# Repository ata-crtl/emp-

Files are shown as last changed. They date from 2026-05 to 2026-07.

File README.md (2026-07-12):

**COMPLETE EMP BUILD**

  This is a low energy through hole electro magnetic pulse generator built for educational purposes.
  It uses inductive Kicback from a simple air core coil to generate broad band pulse that can glitch or reset unshielded digital circuits. Flip the top saftey , then you hold down the trigger for 2 seconds to fire max.



Assembly 1 (19)

Onshape link = https://cad.onshape.com/documents/e3ea2a8dce756d3e28ba0ed2/w/b44164742f645132d3413e84/e/23451d8a78cdce11df78b1ae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
  ---

 ## Table of Contents

- [What is this?](#what-is-this)
- [Why I built it](#why-i-built-it)
- [How it works (in 30 secs)](#how-it-works-in-30-secs)
- [Images and diagrams](#images-and-diagrams)
- [Assembly instructions](#assembly-instructions)
  - [1. Solder the PCB](#1-solder-the-pcb)
  - [2. Wind the coil](#2-wind-the-coil)
  - [3. Prepare the enclosure](#3-prepare-the-enclosure)
  - [4. Final assembly](#4-final-assembly)
- [Safety precautions](#safety-precautions)

---

## What is this?
 A compact, battery powered device that creates a rapid magnetic field collapse,radiating an electro magnetic pulse strong enough to inter fere with nearby digital electronics.It is not a weapon.EDUCTIONAL  USE ONLY

**KEY SPECS**
|parameter|Value|
|---|---|
|Pulse voltage at coil|>200V|
|Effective range |20-30cm(glitch)|
|power supply|3s lipo(11.1v)|
|Max fire time|2 seconds(thermal limit) more = you have 3 seconds to get out  :)|

---

## Why I built it
I always saw lots of tutorials on youtube and always thought how cool they looked.So i thought why not build it, but most of the tutorials on youtube were either weak emps or were very vauge on how to build it.

---
## How it works (in 30 secs)
- 1. A boost converter charges a bank of capacitors to 18V
  2. A 555 timer generates a short pulse,when you press the button
  3. That pulse drives a tc4420 gate driver which turns on the mosfet
  4. Current builds up at the air core coil for like a millisecond
  5. when the mosfet turns of the magnetic field collapses
  6. This makes a voltage spike  which goes over 200v and radiates abroad band emp

---

## Images and diagrams




AISelect_20260712_214746_Samsung Notes
AISelect_20260712_220100_Samsung Notes

AISelect_20260712_215529_Samsung Notes
---
## Assembly instructions
Get your pcb made, the gerber files are in the github.All components are marked on the pcb.
 ## 1. Solder the PCB
1. solder in order of hight, solder in resistors(r1-r7),small ceramics(c1,c5,c7)
 - then u1,u2,u3
 - then d1,l1,j1,j2,j3,j4
 - capacitors,c2,c3,c4,c6 . mind the polarity
 - q1 mossfet last
   
  2.clean the board with isopropyl alcohol
   
## 2. Wind the coil

- 1.Cut 40 cm of the 14awg magnet wire

  2.find a 2cm diameter cylinder(pen.pipe ect)

  3.wind 12 tight turns,make sure they touch

  4.slide it of, wrap with electrical tape

  5. leave  5cm at the end and strip the enamel and tin

  6. twist the 2 leads together

  7. measure resistance. should be 1-3 ohms . if lower add a 1 ohm resistor in series.

 ## 3. Prepare the enclosure
  
  -get the 3d printed case and line all the interior walls with copper foil other than the round emmesion  window at the front, cover the grills as well, but they are for heat dissapation.
  
  -overlap the foil and solder for continuity if needed

  ` solder 1 piece of wire to the foil and the other end to j4 for gnd
  
  ## 4. Final assembly
  1.mount the coil inside the case using hot glue,keep the twisted leads pointing towards the pcb area.
 

  2. place the battery in the top compartment , insert the heat set inserts , and screw the lid down, make sure the wires exit throught the bottom, slide on to the top of the case

  3.connect the  off board components.
 
  |Component A |Component B|
  |------------|-----------|
  |battery+|fuse|
  |fuse|master switch|
  |master switch|j2 pin 1 batt+(on pcb)|
  |battery-|j2 pin 2 batt-(on pcb)|
  |j3 pin 1 |one side of button|
  |other side of button|j3 pin2|
  |coil lead one side|j1|
  |coil lead other side|j2|

  4.place the pcb into the case and secure using the mounting holes ,use the m2 screws. 
  5. place the heat set inserts and screw the case shut.
  
----- 
## Safety precautions

. keep body and head 20-30 cm from emission window

.always discharge the coil after use, do not touch the coil while on

.do not use near pace makers , medical implants or sensitive lab equipment.

.keep a class c fire extinguisher nearby.

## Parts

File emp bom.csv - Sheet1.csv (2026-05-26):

Refrence | part | amount | Price(£) | link
pcb hardware
J1 | 2 pin screw terminal,5.08 pitch,throught hole | 1 | 0.99 | https://www.aliexpress.com/i/1005001666625465.html
J2 | 2 pin screw terminal,5.08 pitch,throught hole | 1 | 0.99 | https://www.aliexpress.com/i/1005001666625465.html
J3 | 2 pin screw terminal,2.54 pitch,throught hole | 1 | 1.9 | https://www.aliexpress.com/item/1005003629262239.html
J4 | 1 pin header | 1 | 0.97 | https://www.aliexpress.com/item/1005005574179742.html?curPageLogUid=yeicRqOfbt8m
F1 | 2A,slow blow fuse + inline fuse holder | 1 | 0.99 | https://www.aliexpress.com/item/1005010608703257.html?curPageLogUid=fXvsTCpmPWWg
s1 | spst toggle switch | 1 | 2.32 | https://www.aliexpress.com/item/1005005937082827.html?curPageLogUid=6XKZixc4s9eP
s2 | spst momentory push button | 1 | 0.64 | https://www.aliexpress.com/item/1005003807410534.html?curPageLogUid=glqdG6u9VZ9A
 | copper foil tape,50mm width | 1 | 4.14 | https://www.aliexpress.com/item/1005010583224519.html?curPageLogUid=0fm7rii8FB44
semi conductor
u1 | MC34063AP(boost converter) | 1 | 1.26 | https://www.aliexpress.com/item/1005006918896712.html?curPageLogUid=9I1loV7CMcEy
u2 | NE555p(timer) | 1 | 0.99 | https://www.aliexpress.com/item/1005009339787324.html?curPageLogUid=8c7hu84e4vEP
u3 | TC4420CPA(mossfet driver) | 1 | 4 | https://www.aliexpress.com/item/1005012098576784.html?curPageLogUid=bTsjEHy7RS4a
q1 | IRFZ44N | 1 | 1.91 | https://www.aliexpress.com/item/1005008166831325.html?curPageLogUid=RhivqrCw4G5N
d1 | 1N5819 | 1 | 1.88 | https://www.aliexpress.com/item/1005007807556976.html?curPageLogUid=4kmR76PxKqoo
INDCTORS
l1 | 100uH ,1a rated radial | 1 | 0.51 | https://www.aliexpress.com/item/1005006119088521.html?curPageLogUid=Kxf2YZgyrdYX
RESISTORS
r1 | 022 ohms , 2w,axial | 1 | 0.66 | https://www.aliexpress.com/item/1005007170526978.html?curPageLogUid=4bHxNJmETjqF
r2 | 10k ohms , 1/4 w | 1 | 0.53 | https://www.aliexpress.com/item/1005002489867848.html?curPageLogUid=B6VLNB2h4Q7c
r3 | 2.2k ohms1/4 w | 1 | 0.5 | https://www.aliexpress.com/item/1005007330288041.html?curPageLogUid=sRkSXITY1tWj
r4 | 100k ohms , 1/4 ohms | 1 | 1.51 | https://www.aliexpress.com/item/1005004002774546.html?curPageLogUid=0lzMdeD4rbJN
r5 | 100k ohms , 1/4 ohms | 1 | 1.51 | https://www.aliexpress.com/item/1005004002774546.html?curPageLogUid=0lzMdeD4rbJN
r6 | 1k ohms, 1/4 W | 1 | 0.53 | https://www.aliexpress.com/item/1005002489867848.html?curPageLogUid=lQjQRgqcIM68
r7 | 10 ohms , 1/4 W | 1 | 1.75 | https://www.aliexpress.com/item/1005004961926843.html?curPageLogUid=z9Hw2ppRmLO0
capacitors
c1 | 1nF , 50V , cermaic | 1 | 0.24 | https://www.aliexpress.com/item/1005003584800244.html?curPageLogUid=2qNeVgppn8vs
c2 | 100uF,25v,electrolytic | 1 | 1.1 | https://www.aliexpress.com/item/1005011631970768.html?curPageLogUid=23NnXv1eUJMF
c3 | 1000uF,25v,electrolytic | 1 | 2.1 | https://www.aliexpress.com/item/1005011631970768.html?curPageLogUid=I1EHWj6nkeq4
c4 | 10uF,25v,electrolytic | 1 | 2.1 | https://www.aliexpress.com/item/1005011631970768.html?curPageLogUid=B362yGf7uz10
c5 | 10nfF,50v,cermaic | 1 | 0.99 | https://www.aliexpress.com/item/1005012084843800.html?curPageLogUid=AVuM1Zd38Yjw
c6 | 10uF,25v,electrolytic | 1 | 2.1 | https://www.aliexpress.com/item/1005011631970768.html?curPageLogUid=42A4ASfGsZrZ
c7 | 0.1uf, 50V,cermaic | 1 | 0.24 | https://www.aliexpress.com/item/1005003584800244.html?curPageLogUid=W8YOUwwpvSf8
 | 14 awg enammell coated copper wire | 1 | 2.37 | https://www.aliexpress.com/item/1005005549459084.html?curPageLogUid=UNJWLOrvq06d
Total |  |  | 42

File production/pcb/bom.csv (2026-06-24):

Designator | Footprint | Quantity | Value | LCSC Part #
C1 | C_Disc_D5.0mm_W2.5mm_P5.00mm | 1 | 1n
C2 | CP_Radial_D6.3mm_P2.50mm | 1 | 100u
C3 | CP_Radial_D10.0mm_P5.00mm | 1 | 1000u
C4, C6 | CP_Radial_D5.0mm_P2.00mm | 2 | 10u
C5 | C_Disc_D4.7mm_W2.5mm_P5.00mm | 1 | 10n
C7 | C_Disc_D5.0mm_W2.5mm_P5.00mm | 1 | 0.1u
D1 | D_DO-41_SOD81_P10.16mm_Horizontal | 1 | 1N5819
J1 | PinHeader_1x02_P2.54mm_Vertical | 1 | COIL
J2 | PinHeader_1x02_P2.54mm_Vertical | 1 | BAT
J3 | PinHeader_1x02_P2.54mm_Vertical | 1 | BTN
J4 | PinHeader_1x01_P2.54mm_Vertical | 1 | FOIL_GND
L1 | L_Axial_L11.0mm_D4.5mm_P15.24mm_Horizontal_Fastron_MECC | 1 | 100u
Q1 | TO-220-3_Vertical | 1 | IRF540N
R1 | R_Axial_DIN0411_L9.9mm_D3.6mm_P12.70mm_Horizontal | 1 | 0.22
R2 | R_Axial_DIN0411_L9.9mm_D3.6mm_P12.70mm_Horizontal | 1 | 10k
R3 | R_Axial_DIN0411_L9.9mm_D3.6mm_P12.70mm_Horizontal | 1 | 2.2k
R4, R5 | R_Axial_DIN0411_L9.9mm_D3.6mm_P12.70mm_Horizontal | 2 | 100k
R6 | R_Axial_DIN0411_L9.9mm_D3.6mm_P12.70mm_Horizontal | 1 | 1k
R7 | R_Axial_DIN0411_L9.9mm_D3.6mm_P12.70mm_Horizontal | 1 | 10
TP1, TP2, TP3 | TestPoint_Pad_D2.0mm | 3 | TestPoint
U1 | DIP-8_W7.62mm | 1 | MC34063AP
U2 | DIP-8_W7.62mm | 1 | NE555P
U3 | DIP-8_W7.62mm | 1 | TC4420CPA

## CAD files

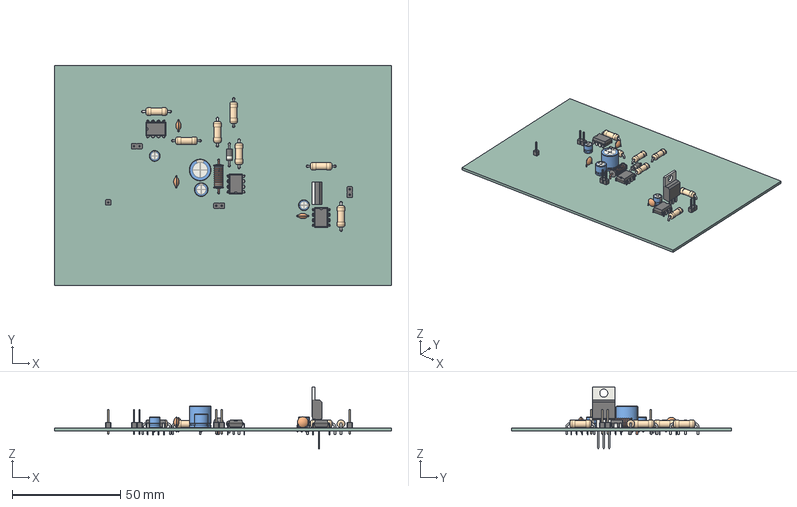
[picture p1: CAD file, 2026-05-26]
pcb/.step
155.7 x 101.8 x 28.5 mm
PinHeader_1x01_P2.54mm_Vertical
CP_Radial_D6.3mm_P2.50mm
L_Axial_L11.0mm_D4.5mm_P15.24mm_Horizontal_Fastron_MECC
TO-220-3_Vertical
R_Axial_DIN0411_L9.9mm_D3.6mm_P12.70mm_Horizontal x 7
PinHeader_1x02_P2.54mm_Vertical x 3
C_Disc_D5.0mm_W2.5mm_P5.00mm x 2
DIP-8_W7.62mm x 3
CP_Radial_D10.0mm_P5.00mm
CP_Radial_D5.0mm_P2.00mm x 2
D_DO-41_SOD81_P10.16mm_Horizontal
C_Disc_D4.7mm_W2.5mm_P5.00mm
emp_PCB

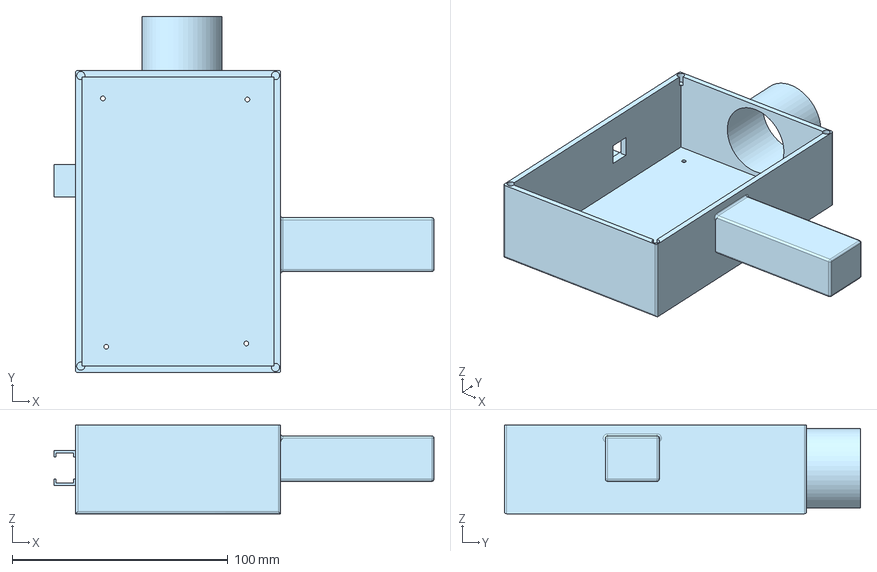
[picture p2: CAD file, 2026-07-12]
production/cad/Part Studio 1.step
176.0 x 165.0 x 41.0 mm

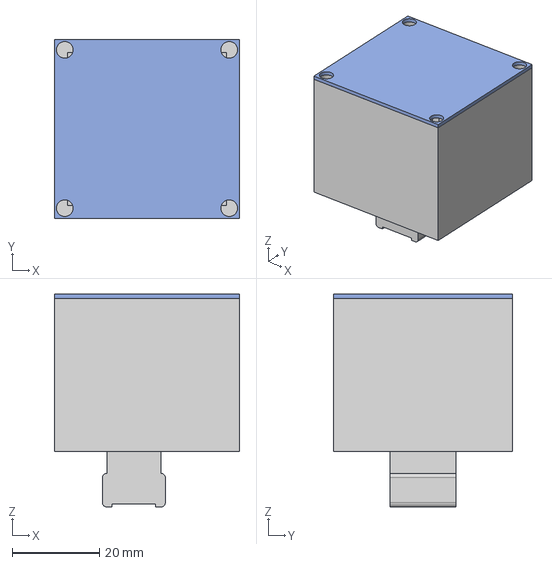
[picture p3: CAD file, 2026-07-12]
production/cad/Part Studio 2.step
42.4 x 41.0 x 48.7 mm

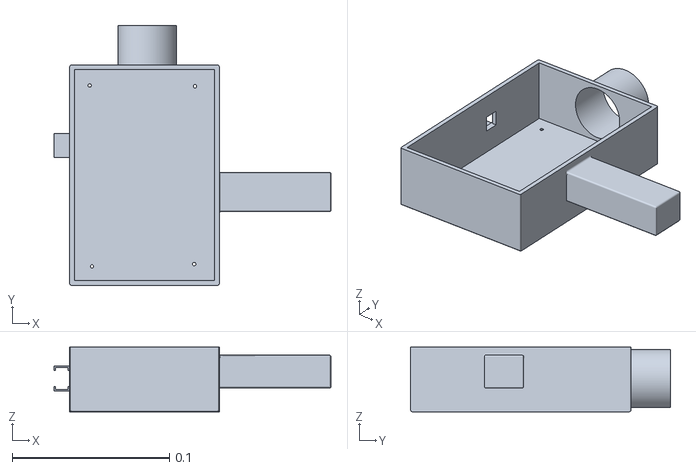
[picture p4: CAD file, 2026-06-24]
production/cad/Part Studio 1 (1).stl
0.176 x 0.165 x 0.041

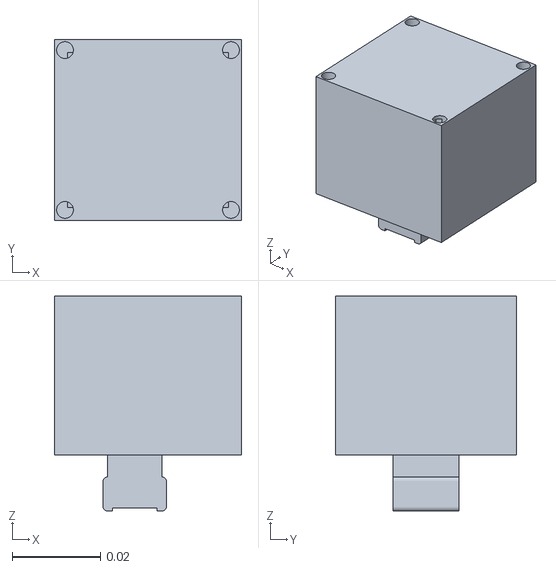
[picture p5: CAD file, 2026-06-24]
production/cad/Part Studio 2 (1).stl
0.0424 x 0.041 x 0.0487

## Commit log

2026-05-26 Update emp bom.csv - Sheet1.csv
    [emp bom.csv - Sheet1.csv]
2026-05-26 Rename emp bom.csv - Sheet1.csv to bom.csv
    [bom.csv]
2026-07-12 Rename emp--a62c514ef43ada493158f1629aa8a829f0f46e96.zip to emp gerbers ect.zip
